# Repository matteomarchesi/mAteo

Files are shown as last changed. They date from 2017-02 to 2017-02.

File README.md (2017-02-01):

# mAteo

mAteo is a small and simple weather station build on Arduino Nano.

It implements measures of temperature, humidity and pressure using DH22 (tempetaure and umidity) and BMP180 (pressure) sensors modules.
It also implements a clock build with "1 wire" approach (
[inspired from here](http://www.instructables.com/id/Make-an-accurate-Arduino-clock-using-only-one-wire/)).
Data are shown on a 0.96" SSD1306 OLED display.
The user can interact with a 5 keys keyboard, build on the basis of Arduino starter kit tutorial, that use only 1 analog input.

Real time data are shown on screen all together.
Graphs of last 24hrs (1 point each 30') are on separated screens.
Data for graph are stored in EEPROM.

## BOM
- Arduino NANO
- DHT22 temperature and humidity sensor
- BMP180 temparture and pressure sensor
- SSD1306 0.96" OLED display
- 5 pushbuttons
- 1 220ohm resistor
- 1 2kohm resistor
- 1 4.7kohm resistor
- 2 10kohm resistors

## Arduino pin used
Single wire clock
- D2 interrupt
- D3 PWM used for clock

keyboard
- A6

I2C
- A4 SDA
- A5 SCL

Power supply of components
- 5V
- GND

Arduino NANO is powerd with onboard USB.

## SW dependencies
- Wire
- SFE_BMP180
- DHT *
- Adafruid_GFX *
- Adafruid_SSD1306 *
- EEPROM

(*) these have been modified to reduce memory footprint and have not been uploaded yet on my github.

## how to use
chapter to be witten

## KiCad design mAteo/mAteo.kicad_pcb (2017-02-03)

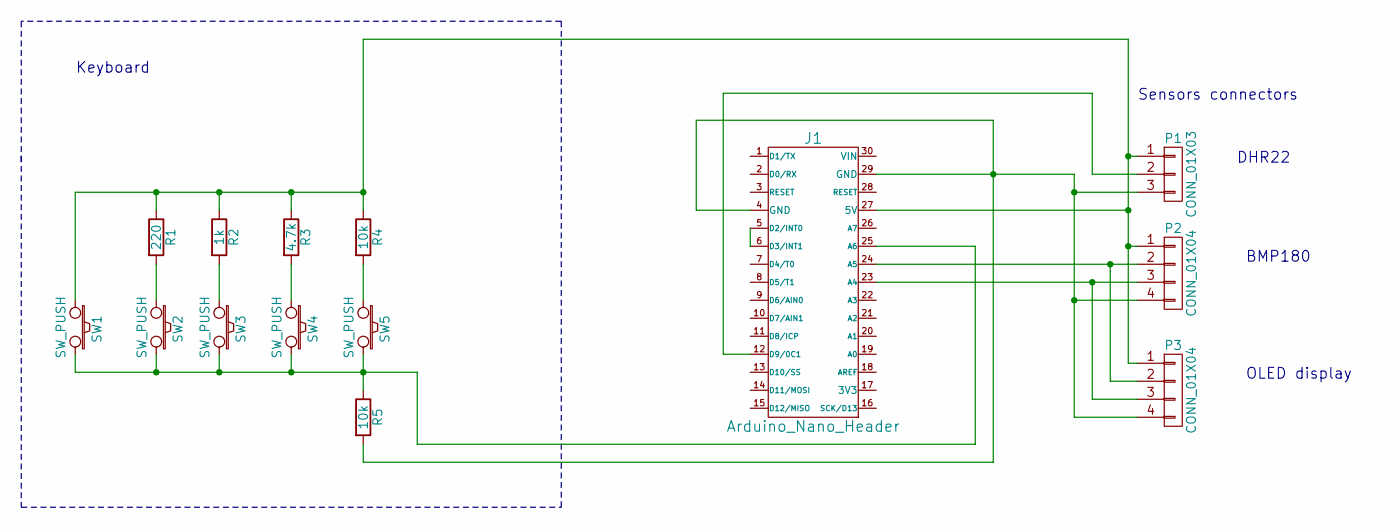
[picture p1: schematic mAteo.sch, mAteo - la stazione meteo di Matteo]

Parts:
J1: Arduino_Nano_Header; arduino_nano_header
P1: CONN_01X03; pin_strip_3
P2, P3: CONN_01X04; pin_strip_4
R1: 220; RC03
R2: 1k; RC03
R3: 4.7k; RC03
R4, R5: 10k; RC03
SW1, SW2, SW3, SW4, SW5: SW_PUSH; PCB_PUSH

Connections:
unnamed: J1.5 (D2/INT0), J1.6 (D3/INT1)
unnamed: J1.12 (D9/0C1), P1.2
unnamed: J1.23 (A4), P2.3, P3.3
unnamed: J1.24 (A5), P2.2, P3.2
unnamed: J1.25 (A6), R5.1, SW1.2, SW2.2, SW3.2, SW4.2, SW5.2
unnamed: J1.27 (5V), P1.1, P2.1, P3.1, R1.1, R2.1, R3.1, R4.1, SW1.1
unnamed: J1.4 (GND), J1.29 (GND), P1.3, P2.4, P3.4, R5.2
unnamed: R1.2, SW2.1
unnamed: R2.2, SW3.1
unnamed: R3.2, SW4.1
unnamed: R4.2, SW5.1

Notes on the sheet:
Keyboard
Sensors connectors
DHR22
BMP180
OLED display

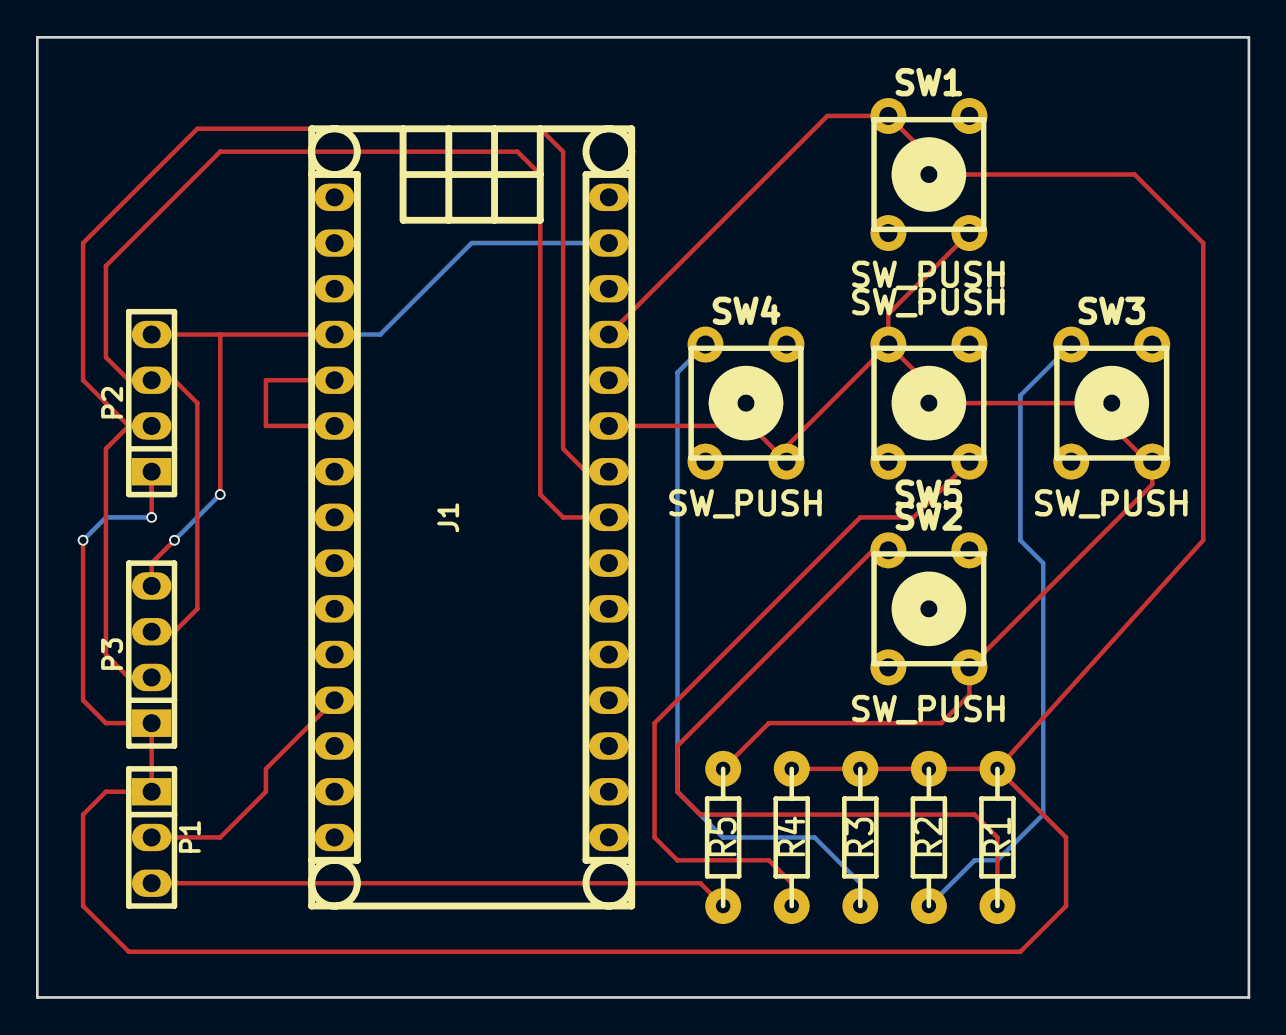
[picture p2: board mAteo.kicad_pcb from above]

Board: 2 copper layers, 67.3 x 53.3 mm, 14 parts (0 on the bottom side), 11 nets.

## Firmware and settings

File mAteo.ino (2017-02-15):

/*
 * mAteo
 * weather station for Arduino UNO/NANO
 *
 * https://github.com/matteomarchesi/mAteo
 * https://matteomarchesi.altervista.org
 * matteo.marchesi71@gmail.com
 *
 */

#define MATEOLIB
//#define DEBUG
#include <SFE_BMP180.h>
#include <Wire.h>
#include <EEPROM.h>

#ifdef MATEOLIB
  #include <mAteo_DHT.h>
  #include <mAteo_GFX.h>
  #include <mAteo_SSD1306.h>
#else
  #include <DHT.h>
  #include <Adafruit_GFX.h>
  #include <Adafruit_SSD1306.h>
#endif

/*
 *  Keyboard
 */

#define KEYPIN A6 
#define KEY1 1023
#define KEY2 1000
#define KEY3 930
#define KEY4 700
#define KEY5 512

/*
 *  Clock definitions 
 *  Connect D2 with D3 on Arduino
 */

uint8_t clockInterrupt = 0; //interrupt 0 is pin 2 on UNO
uint8_t pwmOut = 3; //pin D3

int cyclesPerSecond = 490;

volatile int masterClock = 0;

volatile int8_t seconds, minutes, hours, dd, mm;
volatile int yyyy;

uint8_t mmdds[] = {31,28,31,30,31,30,31,31,30,31,30,31};

String clocktime = ""; 

String printTime2();

/*
 *  DHT22 (temperature and humidity) definitions
 */
#define DHTTYPE DHT22 
#define DHTPIN 9

#ifdef MATEOLIB
  mAteo_DHT dht(DHTPIN, DHTTYPE);
#else
  DHT dht(DHTPIN, DHTTYPE);
#endif
/*
 *  BMP180 (temperature and pressure) definitions
 */

SFE_BMP180 pressure;

/*
 *  SSD1306 display definitions
 *  
 *  char size 6x8
 *  rows start at 0, 8, 16, 24 
 *  
 *  +---------------------+
 *  |Temp:  21.5 C B: 9.0V|
 *  |RH:    42.3%         |
 *  |Pre: 1000.1mb        |
 *  | 16:05:38 02/12/2017 |
 *  +---------------------+
 *
     *012345678901234567890*
     ***********************
 *  
 */

#define OLED_RESET 4
#ifdef MATEOLIB
  mAteo_SSD1306 display(OLED_RESET);
#else
  Adafruit_SSD1306 display(OLED_RESET);
#endif

unsigned int monitoroff = 10000;

  char status;
  double P, h, t;
//  double T;

/*
 *   grafici
 */

#define DATASTORED 48
#define DATASTOREDSIZE 6
uint8_t mempointer;

typedef struct {
  int tem;
  int hum;
  int pre;
} graph_data;

graph_data gdata;

uint8_t stored = 0;

/*
 *  altro
 */

unsigned long previous = 0;
unsigned long previousm = 0;
const int interval = 4000;

void schermo();

void spento();

void tupo(); //temperatura umidità pressione ora

void graphE();

void set_clock();

void readSensors();

uint8_t tastiera();

int8_t funzione = 0;
uint8_t premuto = 0;
/*
 *  0 = spento
 *  1 = t/h/p + ora
 */

void setup() {
#ifdef DEBUG
  Serial.begin(9600);
  Serial.println("... on ...");
#endif
/*  
 *   Clock setup
 */

  String ora = __TIME__;
  String data = __DATE__;
  seconds = ora.substring(6,8).toInt();
  minutes = ora.substring(3,5).toInt();
  hours = ora.substring(0,2).toInt();

  dd = data.substring(4,6).toInt();
  yyyy = data.substring(7,11).toInt();
  data = data.substring(0,3);
  if (data=="Jan") {mm=1;}
  if (data=="Feb") {mm=2;}
  if (data=="Mar") {mm=3;}
  if (data=="Apr") {mm=4;}
  if (data=="May") {mm=5;}
  if (data=="Jun") {mm=6;}
  if (data=="Jul") {mm=7;}
  if (data=="Aug") {mm=8;}
  if (data=="Sep") {mm=9;}
  if (data=="Oct") {mm=10;}
  if (data=="Nov") {mm=11;}
  if (data=="Dec") {mm=12;}

  // clockInterrupt is our interrupt, clockCounter() function is called when invoked on a RISING clock edge
  attachInterrupt(clockInterrupt, clockCounter, RISING);

  delay(2000);
  analogReference(DEFAULT);//not sure if this is needed
  analogWrite(pwmOut, 127); // this starts our PWM 'clock' with a 50% duty cycle

/*  
 *   Display setup
 */
  display.begin(SSD1306_SWITCHCAPVCC, 0x3C);
  display.clearDisplay();
  display.display();
  display.setTextSize(1);
  display.setTextColor(WHITE);
  
  display.setCursor(21,16);
  display.print("Stazione mAteo");
  display.display();
  delay(500);

/*  
 *   DHT setup
 */
  pinMode(1,INPUT);
  
/*  
 *   BMP setup
 */
  pressure.begin();
/*  if (pressure.begin())
    Serial.println("BMP180 init success");
  else
  {
    Serial.println("BMP180 init fail");
    while(1); // Pause forever.
  }
*/
/*
 * reset the memory
  gdata.tem = 0;
  gdata.hum = 0;
  gdata.pre = 0;
*/  
  EEPROM.get(1023,mempointer);

// reset EEPROM id mempoiter doesn't make sense (1st startup or memory corrupted)
  if (mempointer>(DATASTORED-1)){
    mempointer = 0;
    gdata.tem = 0;
    gdata.hum = 0;
    gdata.pre = 0;
    for (int8_t i = 0; i < DATASTORED; i++){
      EEPROM.put(i,gdata);
    }
  }

}

void loop() {
  unsigned long current = millis();
  
  if (current - previous >= interval) {
    previous = current;
    readSensors();   
  }

//  if (current - previousm >= monitoroff) {
//    previousm = current;
//    funzione = 0;   
//  }

  premuto = tastiera();
  switch(premuto) {
    case 1:
      funzione ++;
      break;
    case 2:
      funzione --;
      break;
    case 5:
      funzione = 5;
      break;
    default:
      break;
  }
  schermo();

  
}

void readSensors(){
  h = dht.readHumidity();
  t = dht.readTemperature();

/*  status = pressure.startTemperature();
  if (status != 0)
  {
    // Wait for the measurement to complete:
    delay(status);
    status = pressure.getTemperature(T);
  }
*/
  status = pressure.startPressure(3);
  if (status != 0)
  {
    // Wait for the measurement to complete:
    delay(status);
    status = pressure.getPressure(P,t);
  }

//  if (((seconds == 0) || (seconds == 5) || (seconds == 10) || (seconds == 15) || (seconds == 20) || (seconds == 25) || (seconds == 30) || (seconds == 35) || (seconds == 40) || (seconds == 45) || (seconds == 50) || (seconds == 55)) && (stored == 0)) {
  if ((minutes == 0) || (minutes == 30)){
      if (stored == 0) {
        gdata.tem = (int) (t*10);
        gdata.hum = (int) (h*10);
        gdata.pre = (int) P; // no decimal
        EEPROM.put(mempointer*DATASTOREDSIZE,gdata);
        mempointer++;
  	    if(mempointer==DATASTORED){mempointer=0;}
        EEPROM.put(1023,mempointer);
        stored = 1;
        }
  } else
      stored = 0;
}

void schermo()
  {
    switch (funzione) {
      case 0:
        spento();
        break;
      case 1:
        tupo();
        break;
      case 2:
        graphE(1, "Temperatura (dC)", 1, mempointer);
        break;
      case 3:
        graphE(2, "Umidita' (%RH)", 1, mempointer);
        break;
      case 4:
        graphE(3, "Pressione (mb)", 0, mempointer);
        break;
      case 5:
        set_clock();
        break;
        
      default:
        if (funzione < 0)
          {
            funzione = 4;
          }
        if (funzione > 4)
          {
            funzione = 0;
          }
          
        break;
    }
}

void spento()
  {
    display.clearDisplay();
    display.display();   
  }

void tupo()
  {
    /***********************
     *Temp:  21.5 C B: 9.0V*
     *RH:    42.3%         *
     *Pre: 1000.1mb        *
     * 16:05:38 02/12/2017 *
     ***********************
     *012345678901234567890*
     ***********************
     */
    display.clearDisplay();
    
    display.setCursor(0,0);
    display.print("Temp: ");
    if ((t>=100)||(t<=-10)){
      display.setCursor(6*6,0); // 100.0 -10.0
    } else if ((t>=10)||(t<0)) {
      display.setCursor(7*6,0); // 10.0 -1.0
    } else {
      display.setCursor(8*6,0); // 1.0
    }
    
    display.print(t,1);
// degree circle
    display.drawPixel(68, 0, WHITE);
    display.drawPixel(69, 0, WHITE);
    display.drawPixel(67, 1, WHITE);
    display.drawPixel(70, 1, WHITE);
    display.drawPixel(68, 2, WHITE);
    display.drawPixel(69, 2, WHITE);
// degree circle
    display.setCursor(12*6,0);
    display.println("C");
    
    display.print("RH:    ");
    display.print(h,1);
    display.println("%");
    
    display.print("Pre: ");
    if (P>=1000){
      display.setCursor(5*6,16); //terza riga (0, 8, 16, 24)
      } else {
      display.setCursor(6*6,16);
      }
    display.print(P,1);
    display.println("mb");

    clocktime = printTime2();
    display.setCursor(6,24);
    display.print(clocktime);
    display.display();
  }

String dataOut(int val, int r)
{
  // r=0 no decimal
  // r=1 1 decimal
  String printData;
  int in = (val/10);
  int de = val - in * 10;
  if (r==1)
    {printData = String(in) + '.' + String(de);}
  else
    {printData = val;};
  
  return printData;
}

int datafromeeprom(int wgraph, graph_data gdata){
  int rd = 0;
  switch (wgraph){
      case 1: // temperatura
        rd = gdata.tem;
        break;
      case 2: // temperatura
        rd = gdata.hum;
        break;
      case 3: // temperatura
        rd = gdata.pre;
        break;
    }
    return rd;
}

void graphE(int wgraph, String message, int r, int mempointer)
  {
	int vmin, vmax, pix, rd;
    float tick;
	graph_data gdata;
    uint8_t pnt, pntp, i, gi;
    // trova min e max nell'array
    // get last data
    if (mempointer==0){
      pnt = 0;
      pntp = DATASTORED-1;
    }else{
      pnt = mempointer;
      pntp = mempointer-1;
    }
    
    EEPROM.get((pntp*DATASTOREDSIZE),gdata);
    rd = datafromeeprom(wgraph,gdata);
    vmin = vmax = rd;
    i = pnt;
    while (i!=pntp){
      EEPROM.get((i*DATASTOREDSIZE),gdata);
      rd = datafromeeprom(wgraph,gdata);
      vmin=min(rd,vmin);
      vmax=max(rd,vmax);
      i++;
      if (i == DATASTORED){i = 0;}
    }

    tick = (vmax - vmin)/19.0;  // 20 lines graph
    if (vmax==vmin) {tick=0.1;};
    display.clearDisplay();
    i = pnt;
	  gi = 0;
    while (gi<DATASTORED){
      EEPROM.get((i*DATASTOREDSIZE),gdata);
      rd = datafromeeprom(wgraph,gdata);
      pix= -1*(((rd-vmin)/tick)-29);
      display.drawPixel(gi, pix, WHITE);
//      Serial.println(i);
      i++;
	    gi++;
      if (i == DATASTORED){i = 0;}
    }

    display.setCursor(0,0);
    display.print(message);
    display.setCursor(90,8);
    display.print(dataOut(vmax, r));
    display.setCursor(90,23);
    display.print(dataOut(vmin, r));

    display.display();
  }


void set_clock()
{
    int stfun = 0;
    
    display.clearDisplay();
    clocktime = printTime2();
    display.setCursor(0,0);
    display.print("Set Time");

    display.setCursor(6,24);
    display.print(clocktime);
    display.display();

    premuto = tastiera();
    switch(premuto) {
      case 3:
        stfun++;
        do {
          premuto = tastiera();

          display.setCursor(0,8);
          display.fillRect(0,8,127,22,0);
          switch(stfun){
            case 1: //hrs
              display.print("hours");
			  display.drawFastHLine(6,21,12, WHITE);
			  display.drawFastHLine(6,22,12, WHITE);
              break;
            case 2: //min
              display.print("minutes");
			  display.drawFastHLine(24,21,12, WHITE);
			  display.drawFastHLine(24,22,12, WHITE);
              break;
            case 3: //sec
              display.print("seconds");
			  display.drawFastHLine(42,21,12, WHITE);
			  display.drawFastHLine(42,22,12, WHITE);
              break;
            case 4: //dd
              display.print("dd");
			  display.drawFastHLine(60,21,12, WHITE);
			  display.drawFastHLine(60,22,12, WHITE);
              break;
            case 5: //mm
              display.print("mm");
			  display.drawFastHLine(78,21,12, WHITE);
			  display.drawFastHLine(78,22,12, WHITE);
              break;
            case 6: //yyyy
              display.print("yyyy");
			  display.drawFastHLine(96,21,24, WHITE);
			  display.drawFastHLine(96,22,24, WHITE);
              break;
            default:
              break;
          };
		  
          display.setCursor(6,24);
          display.fillRect(0,24,127,30,0);
          clocktime = printTime2();
          display.print(clocktime);
          display.display();

          
          switch(premuto){
            case 1:
              switch(stfun){
                case 1: //hrs
                  hours++;
				  if (hours>23){hours=0;}
                  break;
                case 2: //min
                  minutes++;
				  if (minutes>59){minutes=0;}
                  break;
                case 3: //sec
                  seconds=0;
                  break;
                case 4: //dd
                  dd++;
                  if (!((dd == 29) && (mm == 2) && ((yyyy == 2020) || (yyyy == 2024) || (yyyy == 2028) || (yyyy == 2032)))){
					          if (dd>mmdds[mm-1]){dd=1;}
				          }
	                break;
                case 5: //mm
                  mm++;
				  if (mm>12){mm=1;}
                  break;
                case 6: //yyyy
                  yyyy++;
                  break;
                default:
                  break;
              }
              break;          
            case 2:
              switch(stfun){
                case 1: //hrs
                  hours--;
				  if (hours<0){hours=23;}
                  break;
                case 2: //min
                  minutes--;
				  if (minutes<0){minutes=59;}
                  break;
                case 3: //sec
                  seconds=0;
                  break;
                case 4: //dd
                  dd--;
/*
 * missing management of leap year in dd decreemention (should not be a big issue)
 *                  if (!((dd == 29) && (mm == 2) && ((yyyy == 2020) || (yyyy == 2024) || (yyyy == 2028) || (yyyy == 2032)))){
 *					if (dd>mmdds[mm-1]){dd=1}
 *				  }
 */
				  if (dd<0){dd=mmdds[mm-1];}
                  break;
                case 5: //mm
                  mm--;
				  if (mm<0){mm=12;}
                  break;
                case 6: //yyyy
                  yyyy--;
                  break;
                default:
                  break;
              }
              break;          
            case 3:
              stfun++;
              break;          
            case 4:
              stfun--;
              break;          
            case 5:
              stfun=0;
              break;          
            default:
              break;          
          }
        } while (stfun>0);
        break;
      default:
      break;
    }
        
}

void clockCounter() // called by interrupt 0 (pin 2 on the UNO) receiving a rising clock edge PWM
{
  masterClock ++; // with each clock rise add 1 to masterclock count
  if(masterClock == cyclesPerSecond) // 974hz on pin 6, may be 490Hz if you use pin 9 or 10
    {
      seconds ++; // after one cycle add 1 second
      masterClock = 0; //reset clock counter
      
      if(seconds==60)
        {
          minutes++;
          seconds = 0;//reset seconds counter
          
          if(minutes==60)
            {
              hours++;
              minutes = 0;
              if (hours == 24)
                {
                  dd ++;
                  hours = 0;
                  if (dd>mmdds[mm-1])
                  {
                    if (!((dd == 29) && (mm == 2) && ((yyyy == 2020) || (yyyy == 2024) || (yyyy == 2028) || (yyyy == 2032)))) 
                    {
                      mm ++;
                      dd = 1;
                      if (mm>12)
                      {
                        yyyy ++;
                        mm = 1;
                }
              }
            }
          }
        }
      }
    }
  return;
}

String twodigits(int val){
  String td = "";
  if(val<10){
    td = "0";
  }
  td = String(td + val);
  return td;
}

String printTime2(){
  String ct;
  ct = String(twodigits(hours) + ":" + twodigits(minutes) + ":" + twodigits(seconds) + " " + twodigits(dd) + "/" + twodigits(mm) + "/" + twodigits(yyyy));
  return ct;  
}

uint8_t tastiera(){
  int keyp;
  uint8_t pressed = 0;
  delay(100);
  keyp = analogRead(KEYPIN);
#ifdef DEBUG
  if (keyp> 20 ){
    Serial.println(keyp);
  }
#endif  
  if (keyp > KEY1-20 && keyp < KEY1+20){
    pressed = 1;
  }
  if (keyp > KEY2-20 && keyp < KEY2+20){
    pressed = 2;
  }
  if (keyp > KEY3-20 && keyp < KEY3+20){
    pressed = 3;
  }
  if (keyp > KEY4-20 && keyp < KEY4+20){
    pressed = 4;
  }
  if (keyp > KEY5-20 && keyp < KEY5+20){
    pressed = 5;
  }
  return pressed;
}

int float2int(float n) {
	int  rounded = (int) n;
	n = n - rounded;
	if (n>=0.5) {rounded++;}
	return rounded;
}

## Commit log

2017-01-10 ADDED: battery voltage measure function(within readSensors function). FIDED: compiling month assignment.
2017-01-11 FIXED: readsensor --> battery voltage measures now consider the voltage partition ADDED: float2int function --> to round float to nearest int ADDED: batteryICO --> to draw battery icon instead of wri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
    [mAteo.ino]
2017-01-14 mAteo.fzz
    ADDED: mAteo.fzz schematics (include only Arduino nano and keyboard circuitry)
    mAteo.ini
    MODIF: keyboard value.
    removed battery measurement
    [mAteo.fzz]
2017-01-14 mAteo.fzz
    ADDED: "clock" wire
    [mAteo.fzz]
2017-01-15 MODIF: mAteo.fzz completed the schematic and the breadboard
    [mAteo.fzz]
2017-01-16 ADDED: graph for temperature
2017-01-22 ADDED: 3 graphs MODIF: Adafruit libraries cut to reduce memory fotprint (not so useful by the way)
2017-01-23 mAteo.fzz MODIF: DHT pin is now D9
    mAteo.ino
    MODIF: DHT pin is now D9
    FIXED: graph now seems to work correctly
    [mAteo.ino]
2017-01-24 mAteo.ino
    MODIF: array with values for graphs are now stored in EEPROM
    [mAteo.fzz, mAteoAAA.fzz]
2017-01-25 mAteo.ino FIXED: modified approach with EEPROM to reduce writing. Now it use a pointer to address which location to read. The EEPROM "array" is a "circle", i.e. after position 47 there is 0.
    mempointer points to next data to be written
    writes data in position 0, 1, 2 ...
    store position 0 1 2 3 4 5 6 7
    mempointer x-1 x P older data
    for graph |--------------->
    ------->P
    [mAteo.ino]
2017-01-26 mAteo.ino FIXED: ** readSensor correct rollover of mempointer
    ** graphE
    added mempointer within passed parameters
    added few local variables (gdata, gi)
    indexes are now uint_8 (i, gi, pnt, pntp)
    introduced new gi index to correctly manage graphs printout
    [mAteo.ino]
2017-01-30 FIXED: clockCounter() several errors in if () written as (dd = 29) instead of (dd == 29) set_clock() added checks to avoid negative numbers and to exceed the max possibble value
    [mAteo.ino]
2017-01-30 removed unnecessary files
    [mAteoAAA.fzz]
2017-01-30 bug fixed in main branch
    [mAteo.ino]
2017-01-30 more bug fixed in main branch
    [mAteo.ino]
2017-02-01 few control variable changed from int to uint8_t
    printTime is now String printTime2() + String twodigits(int val) to simplify the code
2017-02-01 BUGFIX: mAteo.ino varialbles used for time management changed from uint8_t to int8_t, to correctly manage the set_time
    [mAteo.ino]
2017-02-02 BUGFIX: readSensor() now it should actually store a value each 30 min. I hope...
    [mAteo.ino]
2017-02-02 commented Serial.print
2017-02-03 ADDED schematics in mAteo folder
    [mAteo.kicad_pcb, mAteo.sch]
2017-02-07 fixed comments from git
    [mAteo.ino]
